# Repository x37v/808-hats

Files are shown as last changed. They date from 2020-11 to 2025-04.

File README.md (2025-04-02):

# 808 hihat clone

Based on
[schematic](http://www.ericarcher.net/wp-content/uploads/2014/07/tr-808-hihat-diy-project-revised-dec-2009.pdf)
drawn by [Eric Archer](http://www.ericarcher.net/), which is in turn cloned from the TR-808 Hi Hat.

Drawn in [KiCad 5](http://kicad.org/).

## Mods

* MOTM Power connector
* Trigger conditioning
* Ext audio in
* Noise out
* OH/CH Filtering

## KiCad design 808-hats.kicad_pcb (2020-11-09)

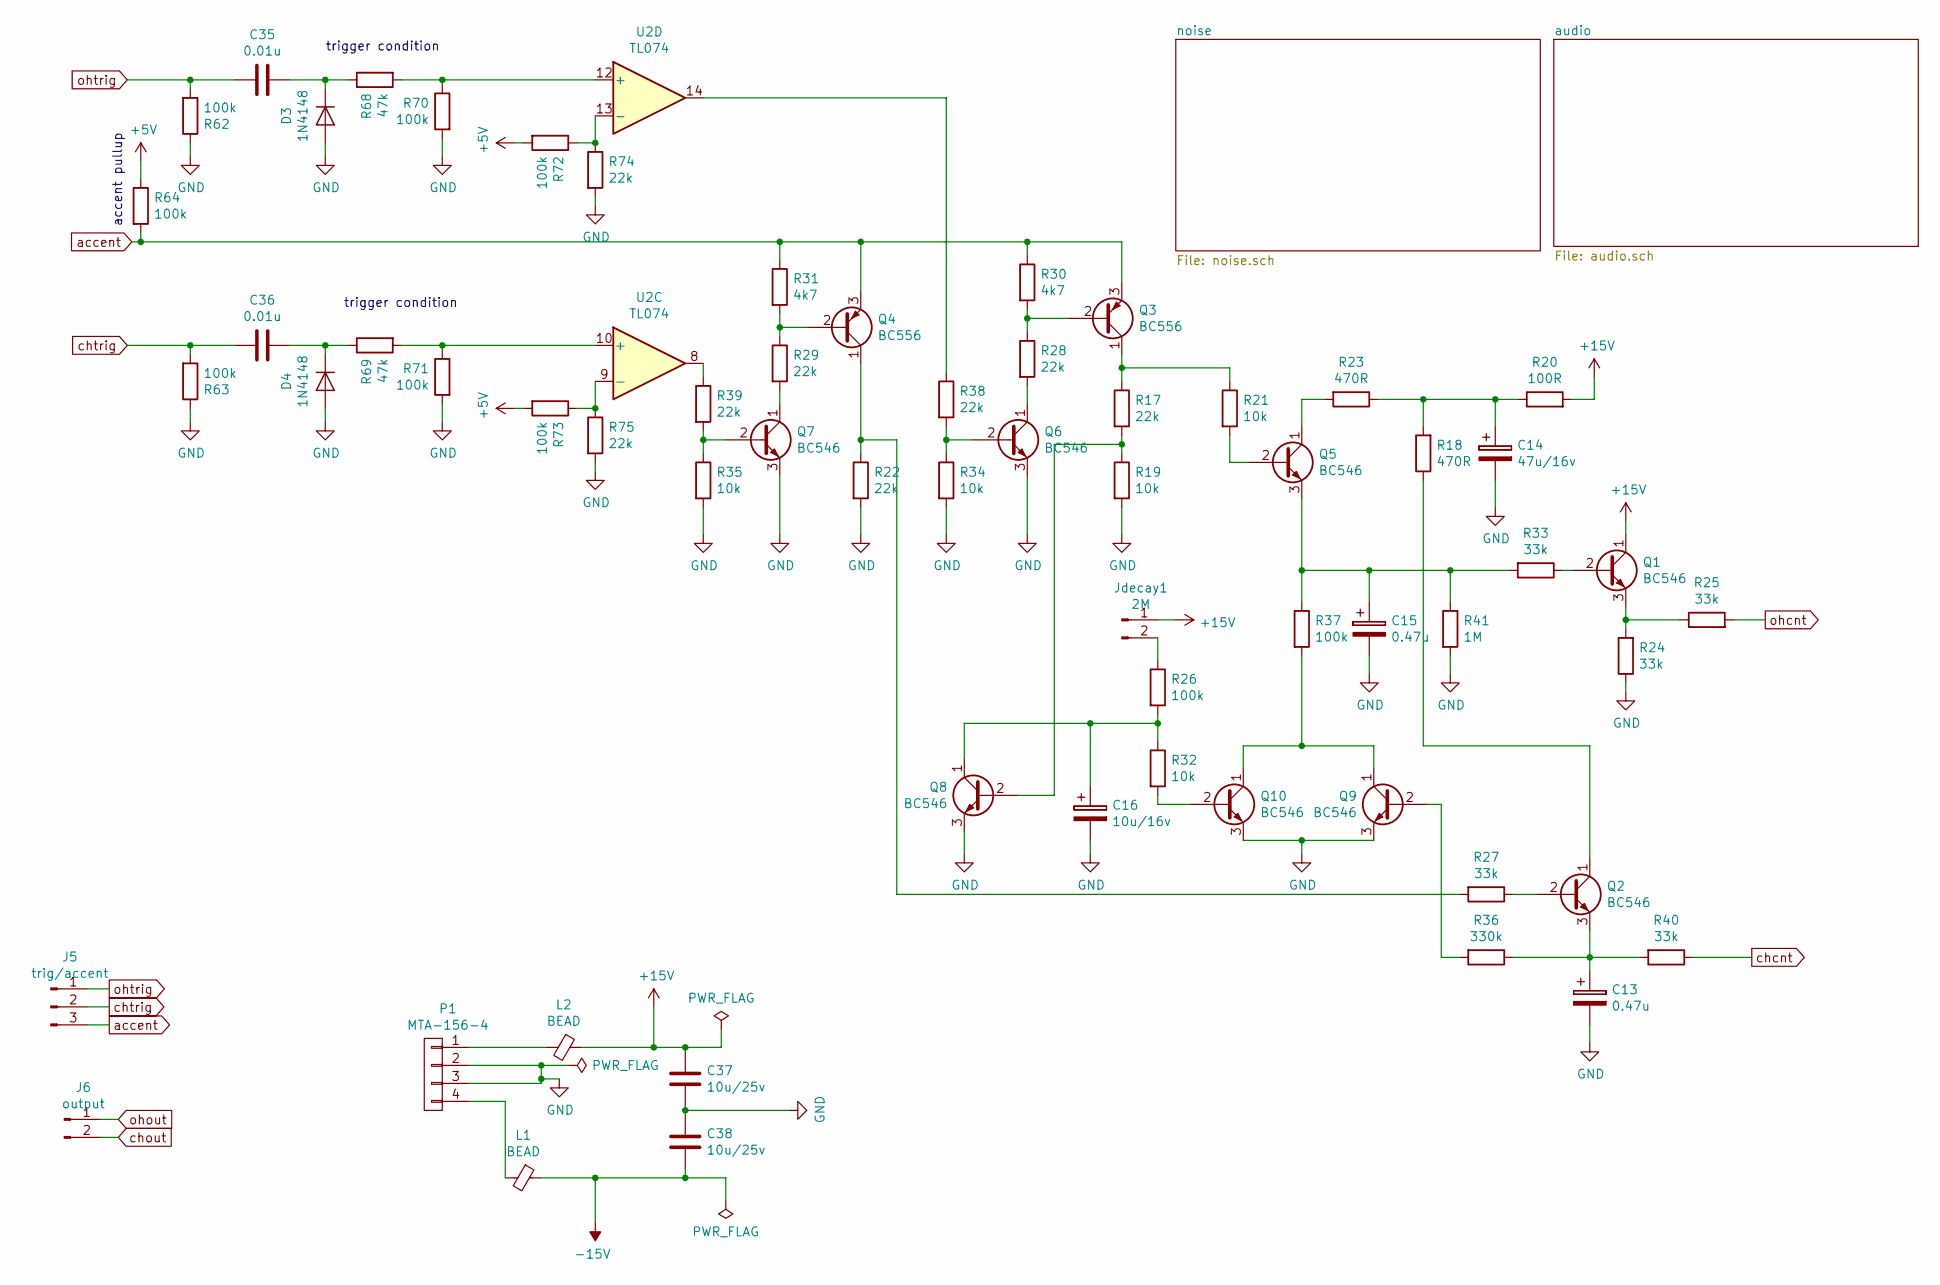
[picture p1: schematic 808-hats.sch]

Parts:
C13, C15: 0.47u; CP_Radial_D7.5mm_P2.50mm
C14: 47u/16v; CP_Radial_D7.5mm_P2.50mm
C16: 10u/16v; CP_Radial_D7.5mm_P2.50mm
C35, C36: 0.01u; C_Rect_L7.2mm_W3.0mm_P5.00mm_FKS2_FKP2_MKS2_MKP2
C37, C38: 10u/25v; C_0805_2012Metric_Pad1.33x1.40mm_HandSolder
D3, D4: 1N4148; D_DO-35_SOD27_P7.62mm_Horizontal
J5: trig/accent; PinHeader_1x03_P2.54mm_Vertical
J6: output; PinHeader_1x02_P2.54mm_Vertical
Jdecay1: 2M; PinHeader_1x02_P2.54mm_Vertical
L1, L2: BEAD; R_Axial_DIN0207_L6.3mm_D2.5mm_P10.16mm_Horizontal
P1: MTA-156-4
Q1, Q2, Q5, Q6, Q7, Q8, Q9, Q10: BC546; TO-92L_Inline
Q3, Q4: BC556; TO-92L_Inline
R17, R22, R28, R29, R38, R39, R74, R75: 22k; R_Axial_DIN0204_L3.6mm_D1.6mm_P7.62mm_Horizontal
R18, R23: 470R; R_Axial_DIN0204_L3.6mm_D1.6mm_P7.62mm_Horizontal
R19, R21, R32, R34, R35: 10k; R_Axial_DIN0204_L3.6mm_D1.6mm_P7.62mm_Horizontal
R20: 100R; R_Axial_DIN0204_L3.6mm_D1.6mm_P7.62mm_Horizontal
R24, R25, R27, R33, R40: 33k; R_Axial_DIN0204_L3.6mm_D1.6mm_P7.62mm_Horizontal
R26, R37, R62, R63, R64, R70, R71, R72, R73: 100k; R_Axial_DIN0204_L3.6mm_D1.6mm_P7.62mm_Horizontal
R30, R31: 4k7; R_Axial_DIN0204_L3.6mm_D1.6mm_P7.62mm_Horizontal
R36: 330k; R_Axial_DIN0204_L3.6mm_D1.6mm_P7.62mm_Horizontal
R41: 1M; R_Axial_DIN0204_L3.6mm_D1.6mm_P7.62mm_Horizontal
R68, R69: 47k; R_Axial_DIN0204_L3.6mm_D1.6mm_P7.62mm_Horizontal
U2: TL074; DIP-14_W7.62mm_LongPads

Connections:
+5V: R64.1, R72.2, R73.2; also elsewhere on the board
+15V: C37.1, Jdecay1.1, L2.1, Q1.1 (C), R20.2; also elsewhere on the board
-15V: C38.2, L1.1; also elsewhere on the board
GND: C13.2, C14.2, C15.2, C16.2, C37.2, C38.1, D3.2 (A), D4.2 (A), P1.2, P1.3, Q6.3 (E), Q7.3 (E), Q8.3 (E), Q9.3 (E), Q10.3 (E), R19.2, R22.2, R24.1, R34.2, R35.2, R41.2, R62.1, R63.1, R70.2, R71.2, R74.2, R75.2; also elsewhere on the board
unnamed: C13.1, Q2.3 (E), R36.1, R40.2
unnamed: C14.1, R18.2, R20.1, R23.1
unnamed: C15.1, Q5.3 (E), R33.2, R37.1, R41.1
unnamed: C16.1, Q8.1 (C), R26.2, R32.1
unnamed: C35.1, D3.1 (K), R68.1
unnamed: C36.1, D4.1 (K), R69.1
unnamed: Jdecay1.2, R26.1
unnamed: L1.2, P1.4
unnamed: L2.2, P1.1
unnamed: Q1.2 (B), R33.1
unnamed: Q1.3 (E), R24.2, R25.1
unnamed: Q2.1 (C), R18.1
unnamed: Q2.2 (B), R27.1
unnamed: Q3.1 (C), R17.1, R21.1
unnamed: Q3.2 (B), R28.1, R30.2
unnamed: Q4.1 (C), R22.1, R27.2
unnamed: Q4.2 (B), R29.1, R31.2
unnamed: Q5.1 (C), R23.2
unnamed: Q5.2 (B), R21.2
unnamed: Q6.1 (C), R28.2
unnamed: Q6.2 (B), R34.1, R38.2
unnamed: Q7.1 (C), R29.2
unnamed: Q7.2 (B), R35.1, R39.2
unnamed: Q8.2 (B), R17.2, R19.1
unnamed: Q9.2 (B), R36.2
unnamed: Q9.1 (C), Q10.1 (C), R37.2
unnamed: Q10.2 (B), R32.2
unnamed: R38.1, U2.14
unnamed: R39.1, U2.8
unnamed: R68.2, R70.1, U2.12 (+)
unnamed: R69.2, R71.1, U2.10 (+)
unnamed: R72.1, R74.1, U2.13 (-)
unnamed: R73.1, R75.1, U2.9 (-)
accent: J5.3, Q3.3 (E), Q4.3 (E), R30.1, R31.1, R64.2
chcnt: R40.1; also elsewhere on the board
chout: J6.2; also elsewhere on the board
chtrig: C36.2, J5.2, R63.2
ohcnt: R25.2; also elsewhere on the board
ohout: J6.1; also elsewhere on the board
ohtrig: C35.2, J5.1, R62.2

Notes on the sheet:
trigger condition
accent pullup

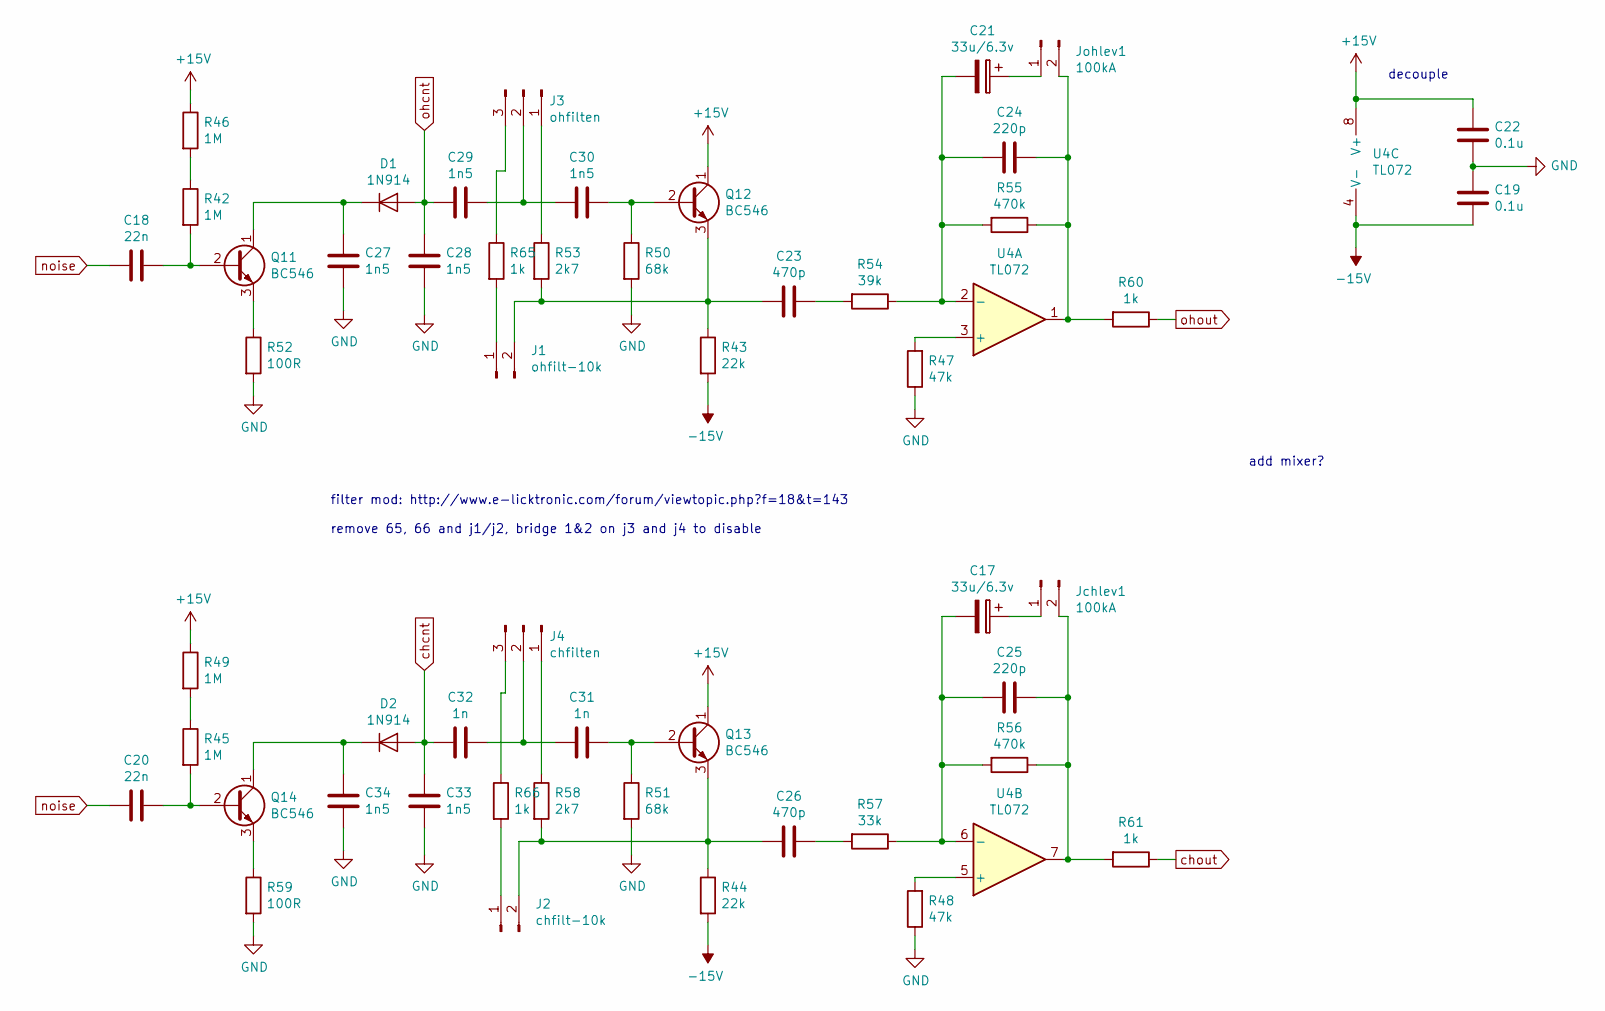
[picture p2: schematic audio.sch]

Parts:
C17, C21: 33u/6.3v; CP_Radial_D7.5mm_P2.50mm
C18, C20: 22n; C_Disc_D4.3mm_W1.9mm_P5.00mm
C19, C22: 0.1u; C_Disc_D3.4mm_W2.1mm_P2.50mm
C23, C26: 470p; C_Disc_D4.3mm_W1.9mm_P5.00mm
C24, C25: 220p; C_Disc_D4.3mm_W1.9mm_P5.00mm
C27, C28, C29, C30, C33, C34: 1n5; C_Disc_D3.4mm_W2.1mm_P2.50mm
C31, C32: 1n; C_Disc_D3.4mm_W2.1mm_P2.50mm
D1, D2: 1N914; D_DO-35_SOD27_P7.62mm_Horizontal
J1: ohfilt-10k; PinHeader_1x02_P2.54mm_Vertical
J2: chfilt-10k; PinHeader_1x02_P2.54mm_Vertical
J3: ohfilten; PinHeader_1x03_P2.54mm_Vertical
J4: chfilten; PinHeader_1x03_P2.54mm_Vertical
Jchlev1: 100kA; PinHeader_1x02_P2.54mm_Vertical
Johlev1: 100kA; PinHeader_1x02_P2.54mm_Vertical
Q11, Q12, Q13, Q14: BC546; TO-92L_Inline
R42, R45, R46, R49: 1M; R_Axial_DIN0204_L3.6mm_D1.6mm_P7.62mm_Horizontal
R43, R44: 22k; R_Axial_DIN0204_L3.6mm_D1.6mm_P7.62mm_Horizontal
R47, R48: 47k; R_Axial_DIN0204_L3.6mm_D1.6mm_P7.62mm_Horizontal
R50, R51: 68k; R_Axial_DIN0204_L3.6mm_D1.6mm_P7.62mm_Horizontal
R52, R59: 100R; R_Axial_DIN0204_L3.6mm_D1.6mm_P7.62mm_Horizontal
R53, R58: 2k7; R_Axial_DIN0204_L3.6mm_D1.6mm_P7.62mm_Horizontal
R54: 39k; R_Axial_DIN0204_L3.6mm_D1.6mm_P7.62mm_Horizontal
R55, R56: 470k; R_Axial_DIN0204_L3.6mm_D1.6mm_P7.62mm_Horizontal
R57: 33k; R_Axial_DIN0204_L3.6mm_D1.6mm_P7.62mm_Horizontal
R60, R61, R65, R66: 1k; R_Axial_DIN0204_L3.6mm_D1.6mm_P7.62mm_Horizontal
U4: TL072; DIP-8_W7.62mm_LongPads

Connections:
+15V: C22.1, Q12.1 (C), Q13.1 (C), R46.1, R49.1, U4.8 (V+); also elsewhere on the board
-15V: C19.2, R43.2, R44.2, U4.4 (V-); also elsewhere on the board
GND: C19.1, C22.2, C27.1, C28.1, C33.1, C34.1, R47.1, R48.1, R50.2, R51.2, R52.2, R59.2; also elsewhere on the board
unnamed: C17.1, Jchlev1.1
unnamed: C17.2, C25.2, R56.2, R57.1, U4.6 (-)
unnamed: C18.1, Q11.2 (B), R42.2
unnamed: C20.1, Q14.2 (B), R45.2
unnamed: C21.1, Johlev1.1
unnamed: C21.2, C24.2, R54.1, R55.2, U4.2 (-)
unnamed: C23.1, J1.2, Q12.3 (E), R43.1, R53.2
unnamed: C23.2, R54.2
unnamed: C24.1, Johlev1.2, R55.1, R60.2, U4.1
unnamed: C25.1, Jchlev1.2, R56.1, R61.2, U4.7
unnamed: C26.1, J2.2, Q13.3 (E), R44.1, R58.2
unnamed: C26.2, R57.2
unnamed: C27.2, D1.1 (K), Q11.1 (C)
unnamed: C29.2, C30.1, J3.2
unnamed: C30.2, Q12.2 (B), R50.1
unnamed: C31.1, C32.2, J4.2
unnamed: C31.2, Q13.2 (B), R51.1
unnamed: C34.2, D2.1 (K), Q14.1 (C)
unnamed: J1.1, R65.2
unnamed: J2.1, R66.2
unnamed: J3.1, R53.1
unnamed: J3.3, R65.1
unnamed: J4.1, R58.1
unnamed: J4.3, R66.1
unnamed: Q11.3 (E), R52.1
unnamed: Q14.3 (E), R59.1
unnamed: R42.1, R46.2
unnamed: R45.1, R49.2
unnamed: R47.2, U4.3 (+)
unnamed: R48.2, U4.5 (+)
chcnt: C32.1, C33.2, D2.2 (A); also elsewhere on the board
chout: R61.1; also elsewhere on the board
noise: C18.2, C20.2; also elsewhere on the board
ohcnt: C28.2, C29.1, D1.2 (A); also elsewhere on the board
ohout: R60.1; also elsewhere on the board

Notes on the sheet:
add mixer?
decouple
filter mod: http://www.e-licktronic.com/forum/viewtopic.php?f=18&t=143 remove 65, 66 and j1/j2, bridge 1&2 on j3 and j4 to disable

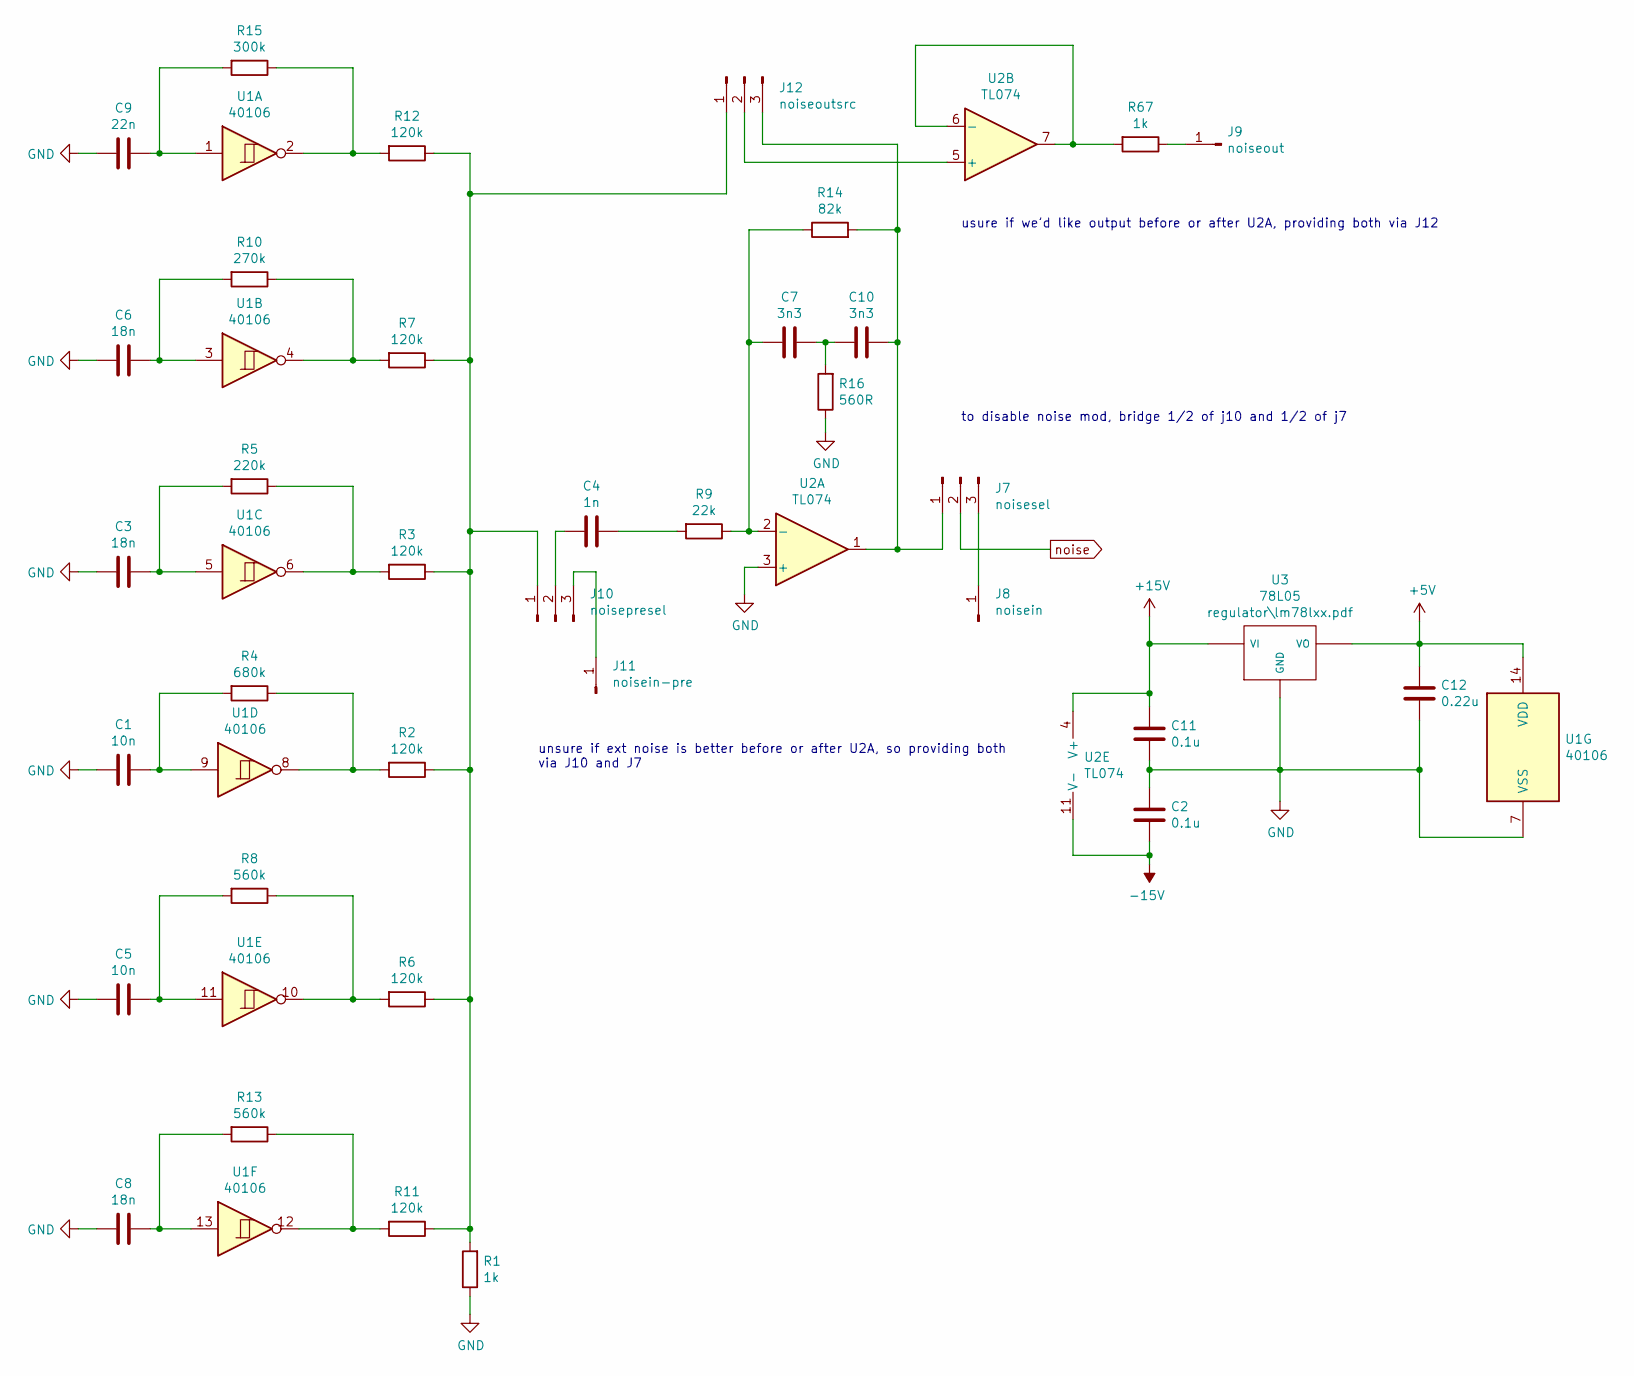
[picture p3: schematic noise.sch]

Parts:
C1, C5: 10n; C_Disc_D3.4mm_W2.1mm_P2.50mm
C2, C11: 0.1u; C_Disc_D3.4mm_W2.1mm_P2.50mm
C3, C6, C8: 18n; C_Disc_D3.4mm_W2.1mm_P2.50mm
C4: 1n; C_Disc_D3.4mm_W2.1mm_P2.50mm
C7, C10: 3n3; C_Disc_D3.4mm_W2.1mm_P2.50mm
C9: 22n; C_Disc_D4.3mm_W1.9mm_P5.00mm
C12: 0.22u; C_Disc_D3.4mm_W2.1mm_P2.50mm
J7: noisesel; PinHeader_1x03_P2.54mm_Vertical
J8: noisein; PinHeader_1x01_P2.54mm_Vertical
J9: noiseout; PinHeader_1x01_P2.54mm_Vertical
J10: noisepresel; PinHeader_1x03_P2.54mm_Vertical
J11: noisein-pre; PinHeader_1x01_P2.54mm_Vertical
J12: noiseoutsrc; PinHeader_1x03_P2.54mm_Vertical
R1, R67: 1k; R_Axial_DIN0204_L3.6mm_D1.6mm_P7.62mm_Horizontal
R2, R3, R6, R7, R11, R12: 120k; R_Axial_DIN0204_L3.6mm_D1.6mm_P7.62mm_Horizontal
R4: 680k; R_Axial_DIN0204_L3.6mm_D1.6mm_P7.62mm_Horizontal
R5: 220k; R_Axial_DIN0204_L3.6mm_D1.6mm_P7.62mm_Horizontal
R8, R13: 560k; R_Axial_DIN0204_L3.6mm_D1.6mm_P7.62mm_Horizontal
R9: 22k; R_Axial_DIN0204_L3.6mm_D1.6mm_P7.62mm_Horizontal
R10: 270k; R_Axial_DIN0204_L3.6mm_D1.6mm_P7.62mm_Horizontal
R14: 82k; R_Axial_DIN0204_L3.6mm_D1.6mm_P7.62mm_Horizontal
R15: 300k; R_Axial_DIN0204_L3.6mm_D1.6mm_P7.62mm_Horizontal
R16: 560R; R_Axial_DIN0204_L3.6mm_D1.6mm_P7.62mm_Horizontal
U1: 40106; DIP-14_W7.62mm_LongPads
U2: TL074; DIP-14_W7.62mm_LongPads
U3: 78L05; TO-220-3_Vertical

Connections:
+5V: C12.1, U1.14 (VDD), U3.3 (VO); also elsewhere on the board
+15V: C11.1, U2.4 (V+), U3.1 (VI); also elsewhere on the board
-15V: C2.2, U2.11 (V-); also elsewhere on the board
GND: C1.2, C2.1, C3.2, C5.2, C6.2, C8.2, C9.2, C11.2, C12.2, R1.1, R16.1, U1.7 (VSS), U2.3 (+), U3.2 (GND); also elsewhere on the board
unnamed: C1.1, R4.2, U1.9
unnamed: C3.1, R5.2, U1.5
unnamed: C4.1, R9.2
unnamed: C4.2, J10.2
unnamed: C5.1, R8.2, U1.11
unnamed: C6.1, R10.2, U1.3
unnamed: C7.2, R9.1, R14.1, U2.2 (-)
unnamed: C8.1, R13.2, U1.13
unnamed: C9.1, R15.2, U1.1
unnamed: C10.1, J7.1, J12.3, R14.2, U2.1
unnamed: C7.1, C10.2, R16.2
unnamed: J7.3, J8.1
unnamed: J9.1, R67.1
unnamed: J10.1, J12.1, R1.2, R2.1, R3.1, R6.1, R7.1, R11.1, R12.1
unnamed: J10.3, J11.1
unnamed: J12.2, U2.5 (+)
unnamed: R2.2, R4.1, U1.8
unnamed: R3.2, R5.1, U1.6
unnamed: R6.2, R8.1, U1.10
unnamed: R7.2, R10.1, U1.4
unnamed: R11.2, R13.1, U1.12
unnamed: R12.2, R15.1, U1.2
unnamed: R67.2, U2.6 (-), U2.7
noise: J7.2; also elsewhere on the board

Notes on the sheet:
unsure if ext noise is better before or after U2A, so providing both via J10 and J7
usure if we'd like output before or after U2A, providing both via J12
to disable noise mod, bridge 1/2 of j10 and 1/2 of j7

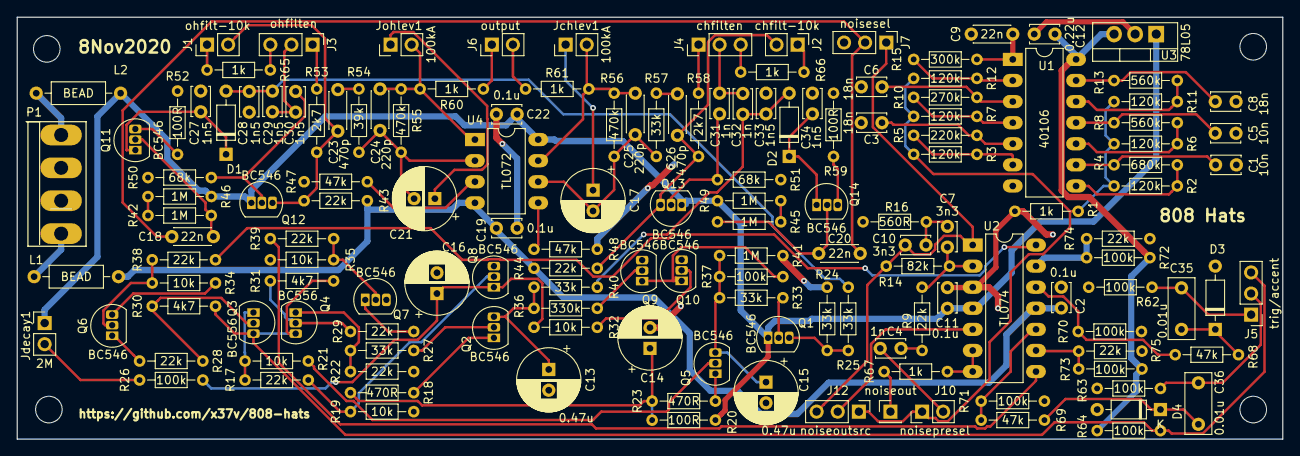
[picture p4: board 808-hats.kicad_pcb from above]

Board: 2 copper layers, 152.4 x 50.8 mm, 149 parts (0 on the bottom side), 96 nets.

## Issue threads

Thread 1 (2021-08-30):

Accent pullup too high

sebastianbeyer, 2021-08-30:
Hey, used your kicad schematic as a basic to simulate the hihats in LTspice! Good stuff! However, I noticed that with the 100k accent pullup there will not be any usable envelope. I am still not sure what to use instead, as I have not yet thought about the interaction once an external CV is connected to the accent. Maybe switched jacks could be used? :-)

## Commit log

2019-04-13 initial commit
    need to add trigger conditioning
    [808-hats.kicad_pcb, 808-hats.sch, audio.sch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]
2019-04-13 added trigger conditioning and accent pullup
    [808-hats.sch, audio.sch, noise.sch]
2019-04-13 added power
    [808-hats.sch, audio.sch, noise.sch]
2019-04-14 fixup noise generator connections
    [808-hats.sch, audio.sch, noise.sch]
2019-04-14 added filter mod
    [audio.sch, noise.sch]
2019-04-14 noise in/out with selection
    [noise.sch]
2019-04-14 noise mods
    [noise.sch]
2019-04-14 indicate kicad
2019-04-14 removed labels
    [noise.sch]
2019-04-27 added hex-inverter style trigger conditioning (amplification?)
    https://static1.squarespace.com/static/54c8f37ae4b015761b133d43/550b9d69e4b0c859c95703b9/550b9d69e4b0c859c95703ba/1426824558402/NeinOhNein_KICK_v1_schem.png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
    [808-hats.sch, noise.sch]
2019-05-03 selected some parts
    [808-hats.sch, audio.sch, noise.sch]
2019-05-04 assigned footprints
    [808-hats.sch, audio.sch, noise.sch]
2019-05-05 oops, through hole for bead
    [808-hats.sch]
2019-05-05 starting layout
    [808-hats.kicad_pcb]
2019-05-06 a lot more layout
    [808-hats.kicad_pcb]
2019-05-07 more layout
    [808-hats.kicad_pcb]
2020-11-08 much layout work
    [808-hats.kicad_pcb]
2020-11-08 exposed and moved around value labels
    [808-hats.kicad_pcb]
2020-11-08 setup design rules
    [808-hats.kicad_pcb]
2020-11-09 fully routed, removed some i/o that could move onto switches
    [808-hats.kicad_pcb]
2020-11-09 labels, .. final layout?
    [808-hats.kicad_pcb]
2021-11-10 Update README.md
    https://forum.kicad.info/t/warning-avoid-all-links-to-kicad-pcb-org-use-kicad-org/31521
